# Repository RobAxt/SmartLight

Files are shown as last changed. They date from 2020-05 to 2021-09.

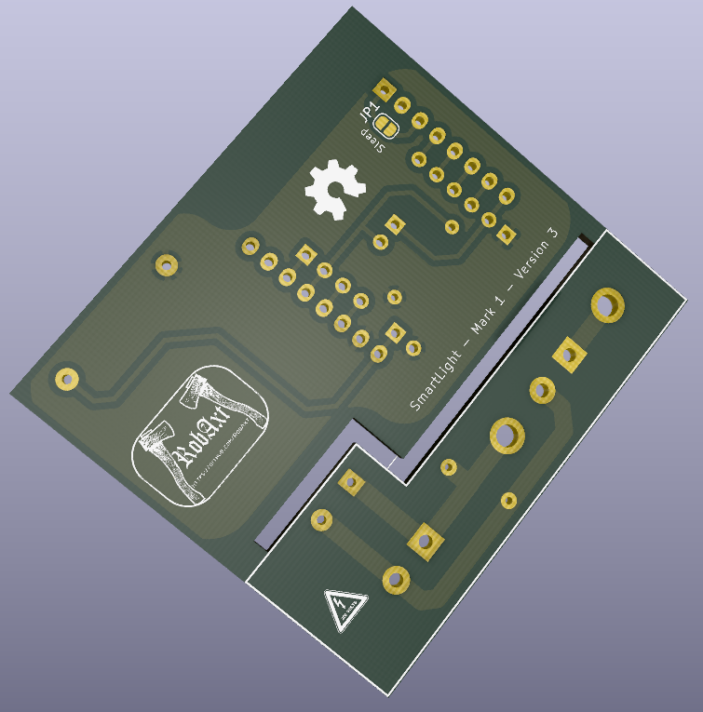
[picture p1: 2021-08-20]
.hwr/Photos/SmartLightBack.png

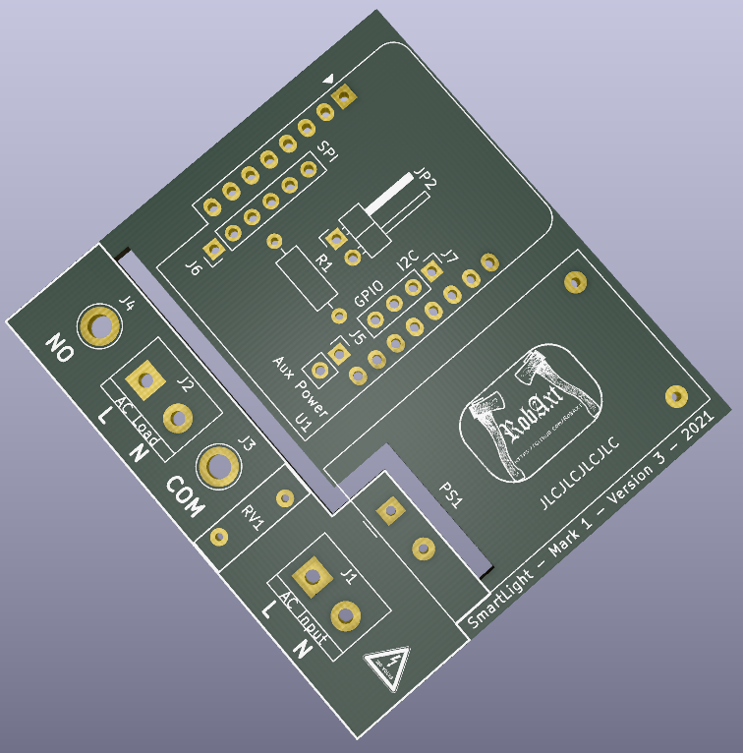
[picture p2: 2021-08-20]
.hwr/Photos/SmartLightFront.png

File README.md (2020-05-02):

# SmartLight :bulb:


Smart Light based on Homie-ESP8266 and Wemos D1 Mini with the Relay Shield

**GPIO:**
* D1: output - To Relay.
* D2: input - From Toggle Button to Locally Toggle Light.
* D3: input - Homie Reset Config.
* D4: output - Homie Status Led.

**Power:** 
* Hi-Link P/N: HLK-5M05

**Hardware Build V2** :construction:
* [Photos](https://photos.app.goo.gl/Z1Gv3g5B6ht62BdJ8)

**3D Design** :construction:
* [TinkerCad](https://www.tinkercad.com/things/h2CH0p7LDbv-relaisbox)

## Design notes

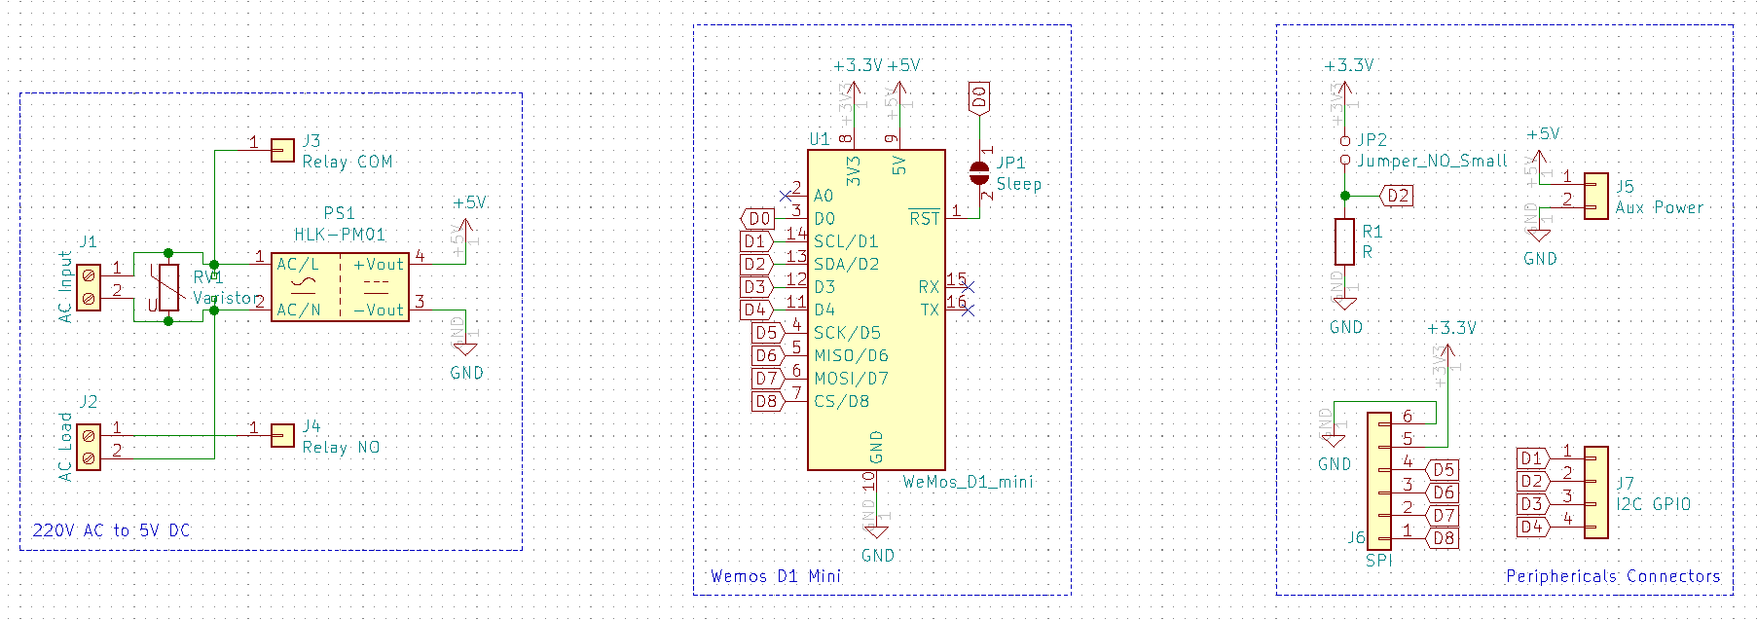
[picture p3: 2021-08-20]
.hwr/Photos/Schematics.png

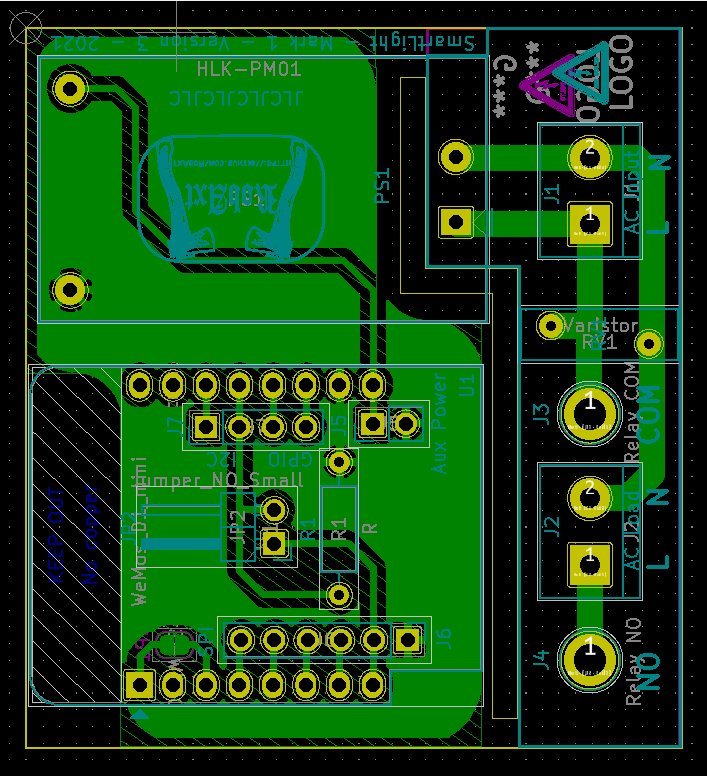
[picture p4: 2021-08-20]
.hwr/Photos/SmartLightPCB.png

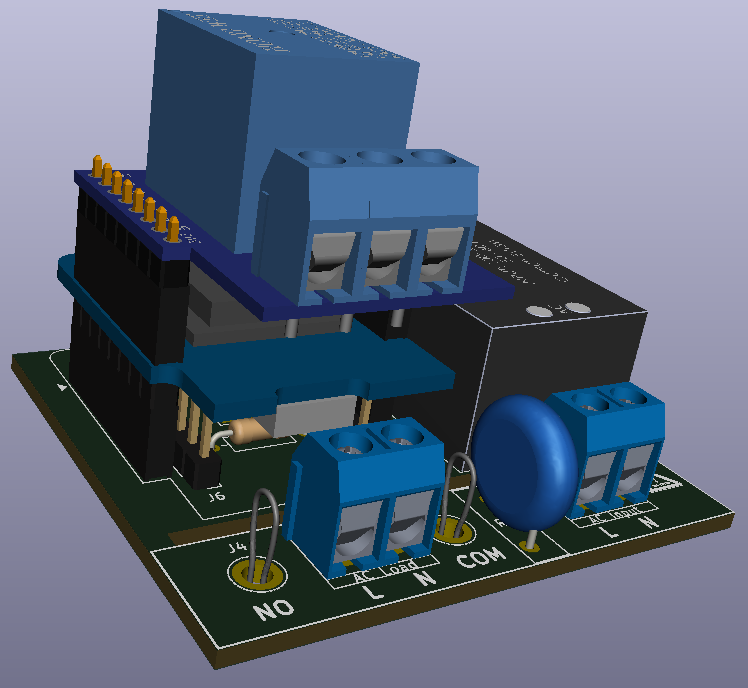
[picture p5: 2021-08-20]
.hwr/Photos/SmartLight2.png

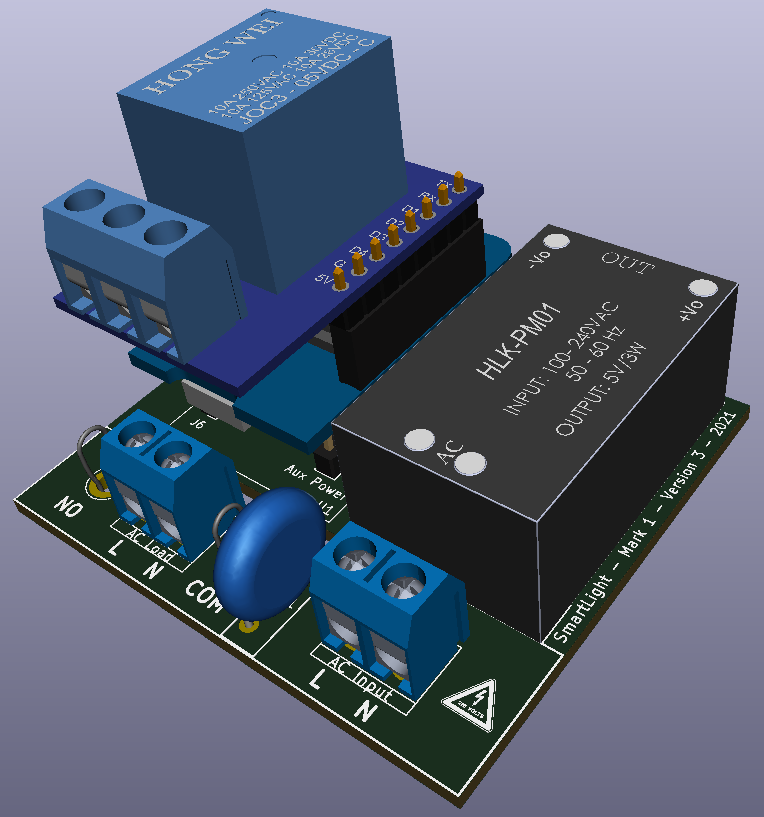
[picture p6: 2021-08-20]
.hwr/Photos/SmartLight1.png

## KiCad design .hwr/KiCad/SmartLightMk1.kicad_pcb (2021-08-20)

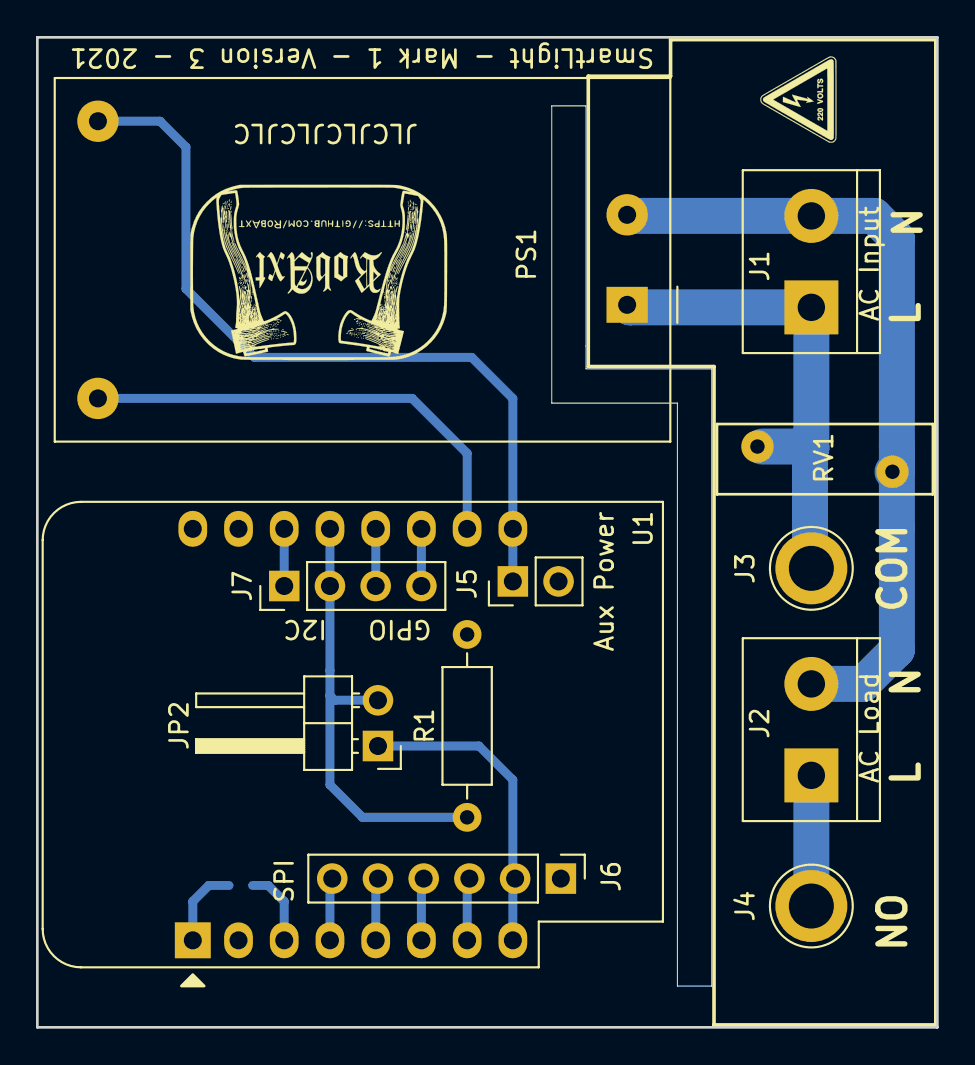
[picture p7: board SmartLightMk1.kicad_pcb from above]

Board: 2 copper layers, 50.0 x 55.0 mm, 13 parts (1 on the bottom side), 16 nets.

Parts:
J1: AC Input; TerminalBlock_bornier-2_P5.08mm
J2: AC Load; TerminalBlock_bornier-2_P5.08mm
J3: Relay COM; TestPoint_Loop_D3.80mm_Drill2.5mm
J4: Relay NO; TestPoint_Loop_D3.80mm_Drill2.5mm
J5: Aux Power; PinHeader_1x02_P2.54mm_Vertical
J6: SPI; PinHeader_1x06_P2.54mm_Vertical
J7: GPIO I2C; PinHeader_1x04_P2.54mm_Vertical
JP1: Sleep; SolderJumper-2_P1.3mm_Open_RoundedPad1.0x1.5mm
JP2: Jumper_NO_Small; PinHeader_1x02_P2.54mm_Horizontal
PS1: HLK-PM01; Converter_ACDC_HiLink_HLK-PMxx
R1: R; R_Axial_DIN0207_L6.3mm_D2.5mm_P10.16mm_Horizontal
RV1: Varistor; RV_Disc_D12mm_W3.9mm_P7.5mm
U1: WeMos_D1_mini; WEMOS_D1_mini_light

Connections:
+3V3: J6.2, JP2.1, U1.8
+5V: J5.1, PS1.4, U1.9
D0: JP1.1, U1.3
D1: J7.1, U1.14
D2: J7.2, JP2.2, R1.1, U1.13
D3: J7.3, U1.12
D4: J7.4, U1.11
D5: J6.6, U1.4
D6: J6.5, U1.5
D7: J6.4, U1.6
D8: J6.3, U1.7
GND: J5.2, J6.1, PS1.3, R1.2, U1.10
unnamed: J1.1, J3.1, PS1.1, RV1.1
unnamed: J1.2, J2.2, PS1.2, RV1.2
unnamed: J2.1, J4.1
unnamed: JP1.2, U1.1

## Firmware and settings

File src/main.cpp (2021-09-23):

#include <Homie.h>
#include <LightNode.hpp>
#include <SyslogStream.hpp>

#define FW_NAME "smart-light"
#define FW_VERSION "1.1.5" 

void onHomieEvent(const HomieEvent & event);

/* Magic sequence for Autodetectable Binary Upload */
const char *__FLAGGED_FW_NAME = "\xbf\x84\xe4\x13\x54" FW_NAME "\x93\x44\x6b\xa7\x75";
const char *__FLAGGED_FW_VERSION = "\x6a\x3f\x3e\x0e\xe1" FW_VERSION "\xb0\x30\x48\xd4\x1a";
/* End of magic sequence for Autodetectable Binary Upload */

LightNode light("light", "Smart Light", "switch");

void setup() {
#if DEBUG_APP
  Serial.begin(SERIAL_SPEED,SERIAL_8N1,SERIAL_TX_ONLY);
  Serial << endl << endl;
  Homie.setLoggingPrinter(&SyslogStream);
  Homie.getLogger() << F("Build Date and Time: ") << __DATE__ << " & " << __TIME__ << endl;
#else
  Homie.disableLogging();
#endif

  Homie_setFirmware(FW_NAME, FW_VERSION); // The underscore is not a typo! See Magic bytes

  //Homie.setSetupFunction([](){});
  Homie.setLoopFunction([](){SyslogStream.loop();});
  //Homie.setBroadcastHandler([](const String& level, const String& value){});
  Homie.onEvent(onHomieEvent);
  Homie.setup();
  SyslogStream.setup(Homie.getConfiguration().mqtt.server.host, Homie.getConfiguration().deviceId, "");
}

void loop() {
  Homie.loop();  
}

void onHomieEvent(const HomieEvent & event) {
  switch (event.type) {
    case HomieEventType::MQTT_DISCONNECTED:
    case HomieEventType::WIFI_DISCONNECTED:
     // WiFi.disconnect();
      break;
    case HomieEventType::SENDING_STATISTICS:
      Homie.getLogger() << F("  • Heap: ") << ESP.getFreeHeap() << endl;
      Homie.getLogger() << F("  • Stack: ") << ESP.getFreeContStack() << endl;
      Homie.getLogger() << F("  • Last reset reason: ") << ESP.getResetInfo() << endl;
      break;
    default:
      break;
  }
}

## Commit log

2020-02-18 Update interruptExample.cpp
    Modifing include line
2020-05-28 Ver.1.1.2 - Switch interrupt enhanced debounce.
2021-08-20 Hardware Files Sent to Production.
    [SmartLightMk1-B_Cu.gbr, SmartLightMk1-B_Mask.gbr, SmartLightMk1-B_SilkS.gbr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]

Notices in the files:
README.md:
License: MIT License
